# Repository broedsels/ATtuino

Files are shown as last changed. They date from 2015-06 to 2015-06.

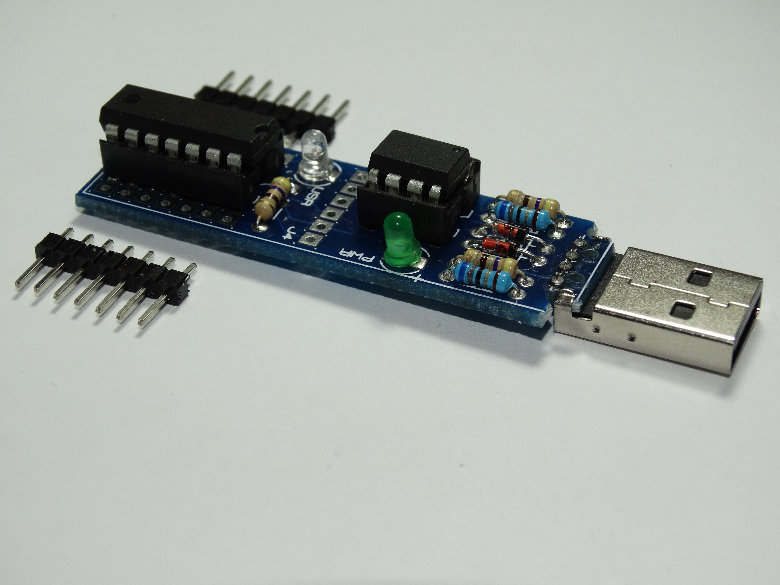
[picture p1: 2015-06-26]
v1.0/DSC02476.JPG

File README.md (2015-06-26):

# ATtuino
The smaller Arduino project board

Based around an ATtiny and a tiny programmer.

V1.0
The first version to be sold on Kickstarter.
It is designed with PTH components only for easy soldering.

V2.0 beta
Changed all components to SMD components. 
Used the standard 6-pin ISP connector.

The programmer part is based upon the V-usb firmware and Design found here: https://tequals0.wordpress.com/2011/09/26/attiny45-based-usbtinyisp-programmer/

The USBtiny software is licensed under the terms of the GNU General Public License as published by the Free Software Foundation, either version 2 of the license, or (at your option) any later version.
http://dicks.home.xs4all.nl/avr/usbtiny/

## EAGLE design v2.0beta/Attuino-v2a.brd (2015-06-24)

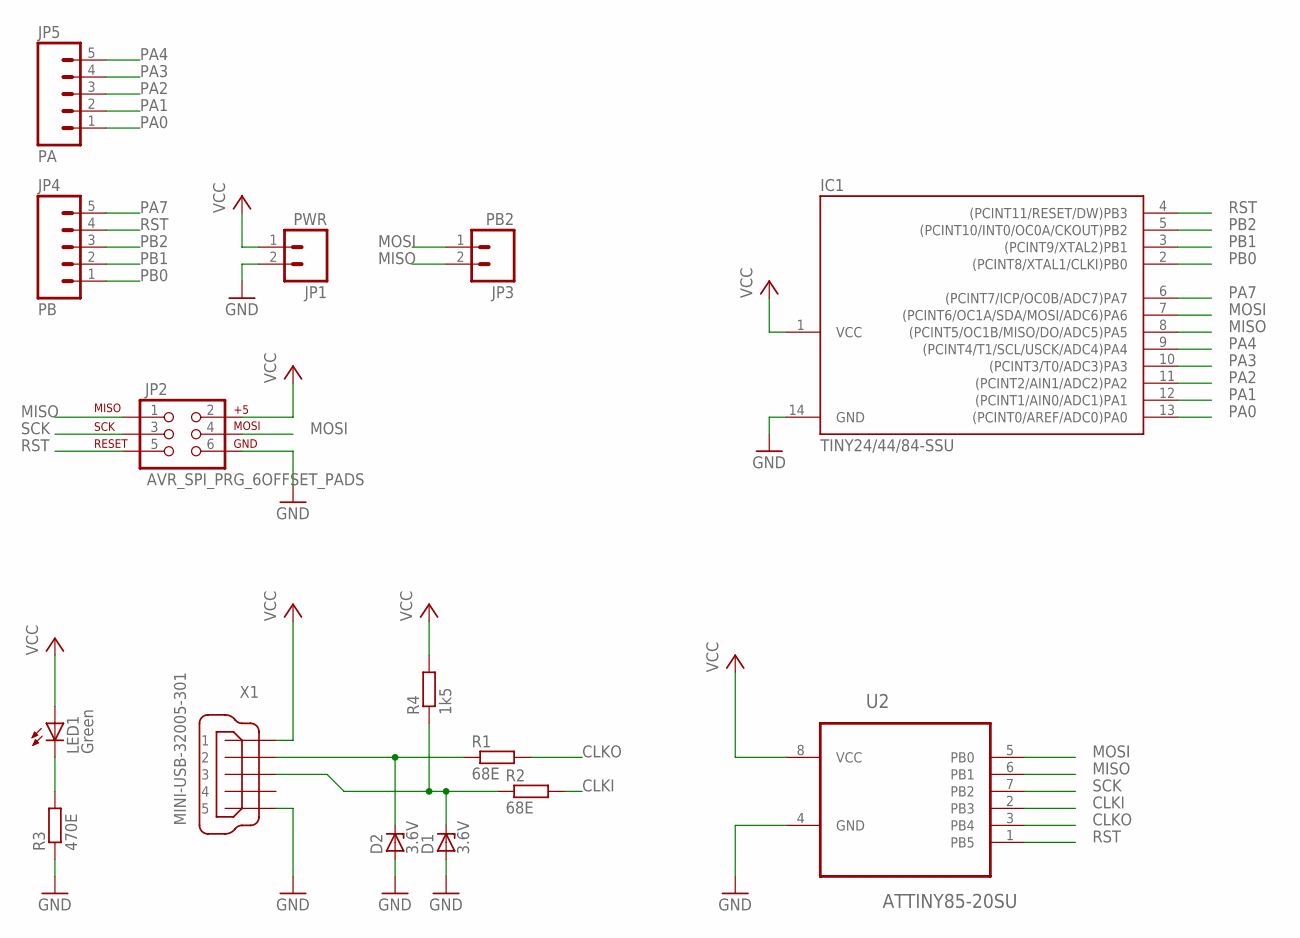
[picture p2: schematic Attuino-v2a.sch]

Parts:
D1, D2: 3.6V; SOD80C
IC1: TINY24/44/84-SSU; SOIC14
JP1: PWR; 1X02_NO_SILK
JP2: AVR_SPI_PRG_6OFFSET_PADS; 2X3_OFFSET
JP3: PB2; 1X02_NO_SILK
JP4: PB; 1X05_NO_SILK
JP5: PA; 1X05_NO_SILK
LED1: Green; LED_1206
R1, R2: 68E; R0805
R3: 470E; R0805
R4: 1k5; R0805
U2: ATTINY85-20SU; SOIC127P798X216-8N
X1: MINI-USB-32005-301; 32005-301

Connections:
CLKI: R2.2, U2.2 (PB3)
CLKO: R1.2, U2.3 (PB4)
GND: D1.A, D2.A, IC1.14 (GND), JP1.2, JP2.6, R3.1, U2.4 (GND), X1.5
MISO: IC1.8 ((PCINT5/OC1B/MISO/DO/ADC5)PA5), JP2.1, JP3.2, U2.6 (PB1)
MOSI: IC1.7 ((PCINT6/OC1A/SDA/MOSI/ADC6)PA6), JP2.4, JP3.1, U2.5 (PB0)
unnamed: D2.C, R1.1, X1.2
unnamed: D1.C, R2.1, R4.1, X1.3
unnamed: LED1.C, R3.2
PA0: IC1.13 ((PCINT0/AREF/ADC0)PA0), JP5.1
PA1: IC1.12 ((PCINT1/AIN0/ADC1)PA1), JP5.2
PA2: IC1.11 ((PCINT2/AIN1/ADC2)PA2), JP5.3
PA3: IC1.10 ((PCINT3/T0/ADC3)PA3), JP5.4
PA4: IC1.9 ((PCINT4/T1/SCL/USCK/ADC4)PA4), JP5.5
PA7: IC1.6 ((PCINT7/ICP/OC0B/ADC7)PA7), JP4.5
PB0: IC1.2 ((PCINT8/XTAL1/CLKI)PB0), JP4.1
PB1: IC1.3 ((PCINT9/XTAL2)PB1), JP4.2
PB2: IC1.5 ((PCINT10/INT0/OC0A/CKOUT)PB2), JP4.3
RST: IC1.4 ((PCINT11/RESET/DW)PB3), JP2.5, JP4.4, U2.1 (PB5)
SCK: JP2.3, U2.7 (PB2)
VCC: IC1.1 (VCC), JP1.1, JP2.2, LED1.A, R4.2, U2.8 (VCC), X1.1

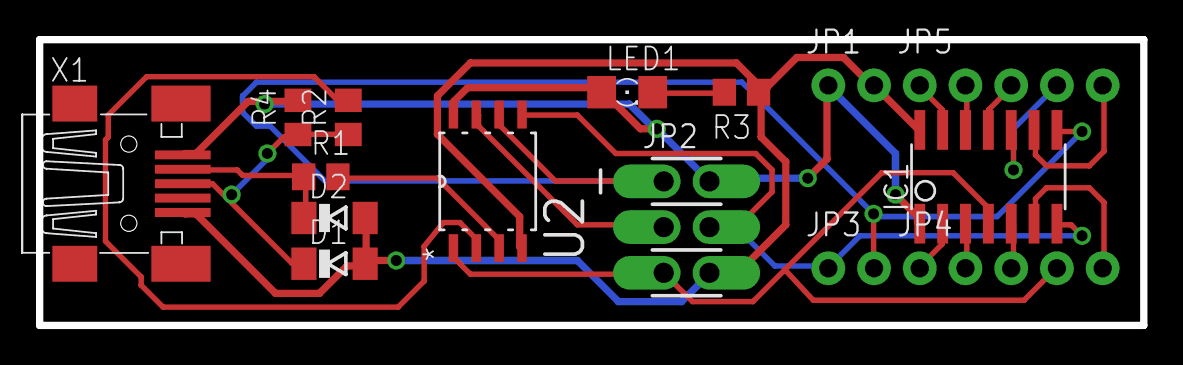
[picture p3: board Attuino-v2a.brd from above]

Board: 2 copper layers, 61.3 x 15.9 mm, 15 parts (0 on the bottom side), 20 nets.

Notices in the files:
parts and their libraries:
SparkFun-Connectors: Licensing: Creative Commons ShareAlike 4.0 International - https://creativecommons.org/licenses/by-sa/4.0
